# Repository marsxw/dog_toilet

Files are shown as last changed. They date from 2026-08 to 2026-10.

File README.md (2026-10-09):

# 狗厕所图纸 & 代码

模组：**ESP32-S3-WROOM-1-N16R8**（16MB Flash + 8MB Octal PSRAM；有时写作 N16S8，指同一类 8MB 外扩 RAM）。

## PC 虚拟环境

完整依赖与复现步骤见 **`environment.txt`**；一键安装：

```powershell
cd c:\Users\Siven\Desktop\dog_toilet
python -m venv venv
.\venv\Scripts\Activate.ps1
pip install -r requirements.txt
```

## 刷 MicroPython（COM3 示例）

须用 **SPIRAM_OCT** 固件，不要用不带 Octal PSRAM 的 `ESP32_GENERIC_S3-*.bin`（否则会报 `PSRAM chip is not connected`）。

```powershell
cd c:\Users\Siven\Desktop\dog_toilet
.\venv\Scripts\Activate.ps1
pip install esptool mpremote

python -m esptool --chip esp32s3 --port COM3 erase_flash
python -m esptool --chip esp32s3 --port COM3 --baud 460800 write_flash -z 0x0 `
  firmware\ESP32_GENERIC_S3-SPIRAM_OCT-20260824-v1.29.0.bin
```

## 上传 Python 到板子（COM3 示例）

先关掉 **bench_gui / Thonny** 等占用串口的程序。端口 `COM3` 按设备管理器修改。

```powershell
cd c:\Users\Siven\Desktop\dog_toilet\firmware
..\venv\Scripts\mpremote.exe connect COM3 soft-reset

..\venv\Scripts\mpremote.exe connect COM3 cp main.py :main.py
..\venv\Scripts\mpremote.exe connect COM3 cp bench.py :bench.py
..\venv\Scripts\mpremote.exe connect COM3 cp pins.py :pins.py
..\venv\Scripts\mpremote.exe connect COM3 cp motor.py :motor.py
..\venv\Scripts\mpremote.exe connect COM3 cp servo_ctrl.py :servo_ctrl.py
..\venv\Scripts\mpremote.exe connect COM3 cp config.py :config.py
..\venv\Scripts\mpremote.exe connect COM3 cp detector.py :detector.py
..\venv\Scripts\mpremote.exe connect COM3 cp web.py :web.py
..\venv\Scripts\mpremote.exe connect COM3 cp test_web.py :test_web.py
..\venv\Scripts\mpremote.exe connect COM3 cp ir_input.py :ir_input.py

..\venv\Scripts\mpremote.exe connect COM3 reset
```

若提示 `could not enter raw repl`，先 `soft-reset` 再 `cp`；若仍失败，按一下板子复位后重试。

## 客户模式 / 工程师模式

上电、断电重启后**默认客户模式**（自动感应冲水）。工程师模式只存在内存里，断电即回到客户模式。

1. 手机连接热点 `toilet_` + MAC 后 6 位（开放、无密码）。
2. **客户配置页：** [http://192.168.99.1](http://192.168.99.1)
3. **工程师测试页：** [http://192.168.99.1/test](http://192.168.99.1/test)  
   ESP32 热点只有一个本机 IP（`192.168.99.1`），工程师入口是该地址下的 `/test`。若写成 `192.168.99.99` 默认到不了板子。
4. **电脑 GUI：** 串口连接后会发 `ENG` 进入工程师模式；也可点「返回客户模式」（`CUST`）。断开串口会回到客户模式。

```powershell
.\venv\Scripts\Activate.ps1
python bench_gui\app.py
```

WiFi 默认开启 30 分钟，超时关闭后需重新上电。

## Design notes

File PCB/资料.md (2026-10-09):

对应板芯片的 MicroPython：[ESP32_GENERIC_S3](https://micropython.org/download/ESP32_GENERIC_S3/)  
模组：**ESP32-S3-WROOM-1-N16R8**（16MB Flash + **8MB Octal PSRAM**；部分资料写 N16S8，含义相同）。不要刷非 S3 固件。

**固件必须选 SPIRAM_OCT 版本**（文件名含 `SPIRAM_OCT`），例如仓库内  
`firmware/ESP32_GENERIC_S3-SPIRAM_OCT-20260824-v1.29.0.bin`。  
若误刷普通 `ESP32_GENERIC_S3-*.bin`，启动会报 `PSRAM chip is not connected` / `Failed to init external RAM`。

开发一个感应狗上厕并完成自动冲水的项目。

硬件：**红外传感器**判断占用；**冲水舵机**拉动冲水杆；**粉碎电机**由驱动芯片正反转；GPIO3 ADC 采电机电流（0.1Ω 采样电阻，放大 10.5 倍）。

## 接线 / GPIO

| 功能 | GPIO | 说明 |
|---|---|---|
| 红外输入 | **1** | 固定数字输入。触发（宠物在）= **高电平**；未触发 = **低电平** |
| 电机电流 ADC | **3** | 采样电阻 0.1Ω，放大 10.5 倍。`I = Vadc / 1.05` |
| 粉碎 IN1 | **11** | 驱动芯片输入。与 IN2 配合正反转，**禁止同时为高** |
| 粉碎 IN2 | **12** | 同上 |
| 冲水舵机 | **13** | 50 Hz PWM，脉宽 500–2500 µs 对应 0–180° |

粉碎电机逻辑：

| IN1 (11) | IN2 (12) | 动作 |
|---|---|---|
| 高 | 低 | 正转（粉碎开） |
| 低 | 高 | 反转 |
| 低 | 低 | 停止 |
| 高 | 高 | **禁止** |

电流超过 `firmware/motor.py` 中 `I_OVERCURRENT_A`（默认 4 A）时，调试模式下会停粉碎电机。

## 冲水动作

1. 舵机转到冲水角 `PRESS_DEG`（默认 90°），等待转动 + 保持
2. 舵机回到回位角 `RELEASE_DEG`（默认 20°）

默认回位 **0°**、按下 **70°**。工程师模式网页或串口 GUI 可改并保存到 `config.json`。

舵机每按下一轮冲水，粉碎剩余时间累加 `crush_s`（默认 **15 s**），电机一直转到剩余为 0。不并入冲水队列。电流超过 4 A 会停粉碎。

一次占用结束若冲水次数 > 1：按上面流程重复，两次之间间隔使用「冲水间隔」。

## 检测与冲水逻辑

空闲 → 占用中（GPIO1 高）→ 离开倒计时（GPIO1 由高变低）→ 冲水 → 空闲

- GPIO1 **高**：宠物在；若正处于离开倒计时，**取消冲水并重新占用**。
- GPIO1 由高变低：宠物离开，开始倒数；倒计时结束才冲水。
- 倒计时期间再次检测到高电平：倒计时清零，回到占用。
- 上电时若 GPIO1 已是低电平，不冲水，保持空闲。
- 冲水过程中电机动作做完再响应下一次检测。

## 客户模式 / 工程师模式

上电默认**客户模式**（自动冲水）。工程师模式不写 flash，断电即恢复客户模式。

| 入口 | 地址 / 操作 |
|---|---|
| 客户配置 | 连热点后打开 **http://192.168.99.1** |
| 工程师测试 | **http://192.168.99.1/test**（舵机 / 粉碎 / 电流） |
| 电脑 GUI | `python bench_gui\app.py`，串口发送 `ENG` 进入工程师模式 |

ESP32 热点本机 IP 只有 **192.168.99.1**，工程师页面是该 IP 的 `/test` 路径。

```powershell
cd c:\Users\Siven\Desktop\dog_toilet
.\venv\Scripts\Activate.ps1
python bench_gui\app.py
```

连接 USB 串口（115200），调节舵机角度、粉碎正反转，并看 GPIO3 电流；测好后改 `RELEASE_DEG` / `PRESS_DEG`。

## 网页（客户）

手机连接 ESP32 热点后打开 **http://192.168.99.1** 配置感应和冲水参数。

- 上电后 WiFi 默认开启 **30 分钟**，超时自动关闭。
- 热点名称：`toilet_` + MAC 后 6 位。
- 参数掉电保存；界面中英文可切换。

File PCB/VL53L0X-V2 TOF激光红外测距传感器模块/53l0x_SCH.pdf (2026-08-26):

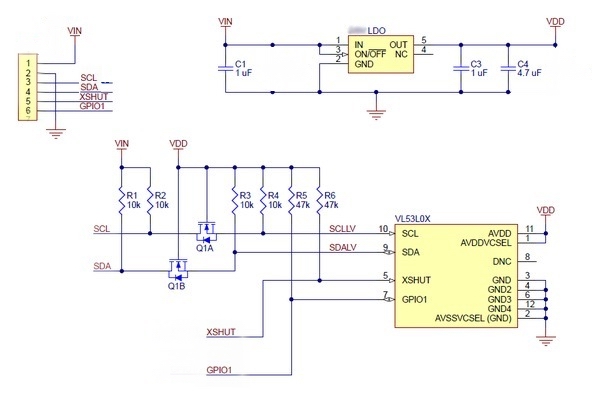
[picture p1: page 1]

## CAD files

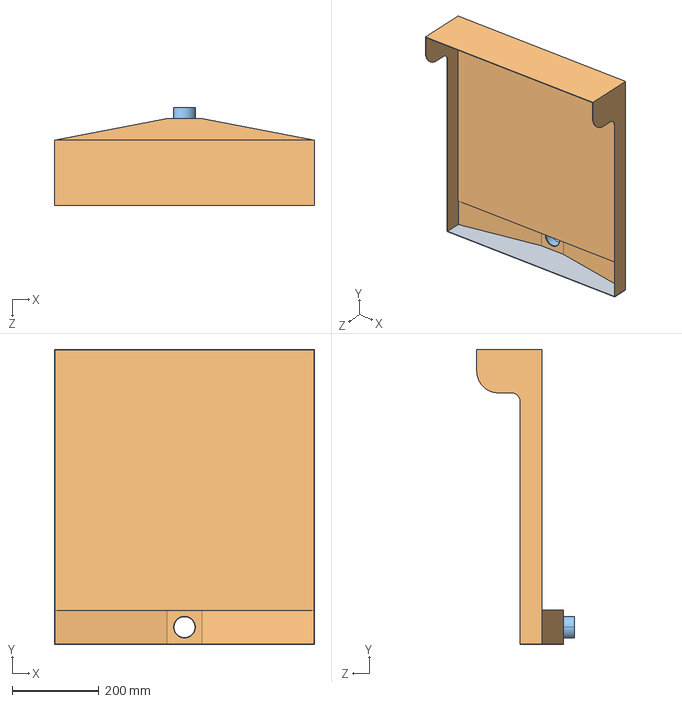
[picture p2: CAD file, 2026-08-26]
机械结构/收集盆v1.STEP
600.0 x 680.0 x 225.0 mm

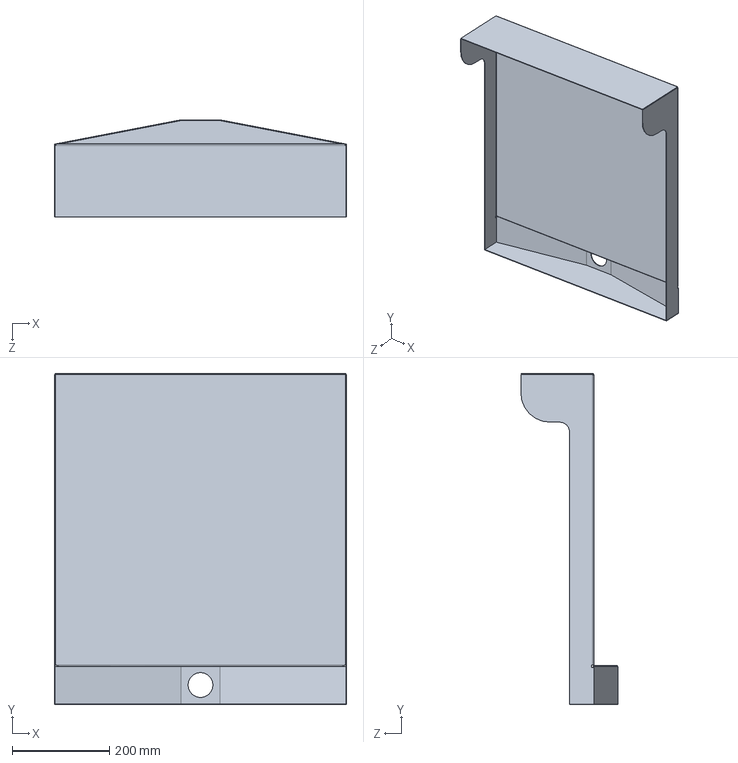
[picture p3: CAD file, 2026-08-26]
机械结构/收集盆_钣金.SLDPRT
600.0 x 680.0 x 200.0 mm

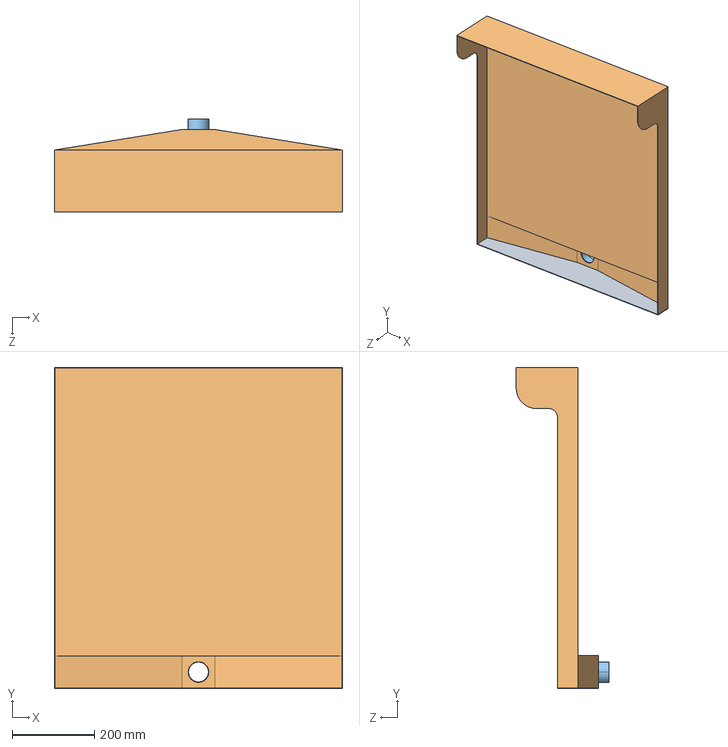
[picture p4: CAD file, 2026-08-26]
机械结构/收集盆70.STEP
700.0 x 780.0 x 225.0 mm

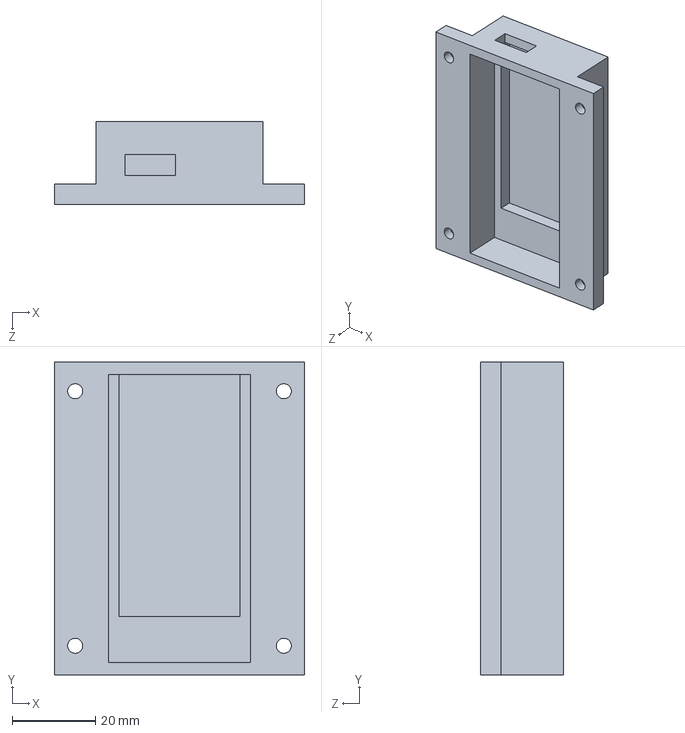
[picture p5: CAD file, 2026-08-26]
机械结构/pcb外壳底.STEP
60.0 x 75.0 x 20.0 mm

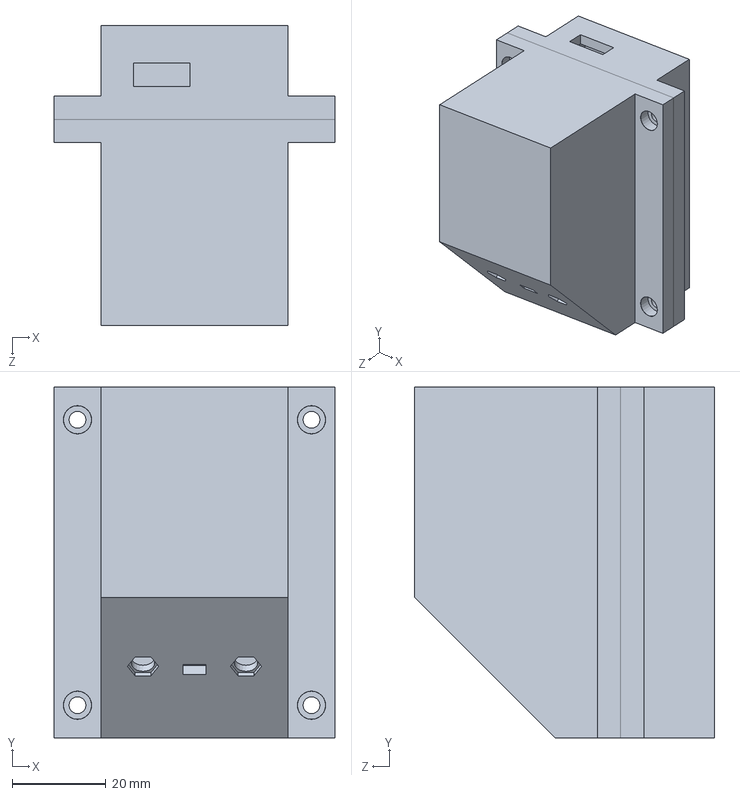
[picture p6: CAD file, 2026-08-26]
机械结构/pcb外盒.SLDPRT
60.0 x 75.0 x 64.0 mm

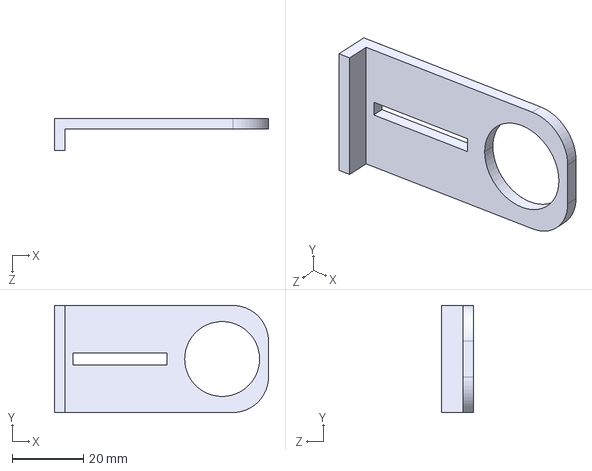
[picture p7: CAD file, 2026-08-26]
机械结构/1.STEP
60.0 x 30.0 x 9.00 mm

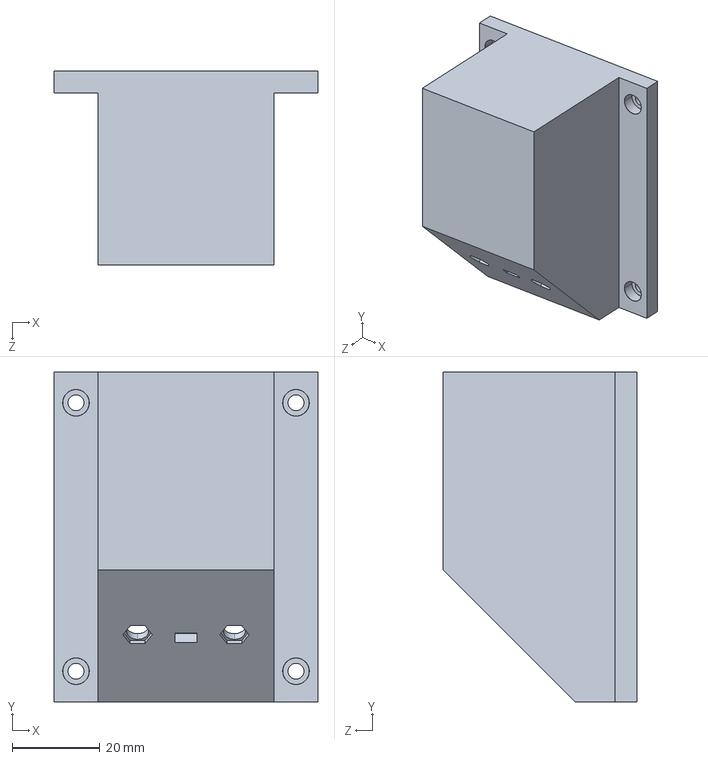
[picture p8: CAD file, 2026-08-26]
机械结构/pcb外壳顶.STEP
60.0 x 75.0 x 44.0 mm

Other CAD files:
机械结构/收集盆.STEP
机械结构/1.SLDPRT
机械结构/pcb外壳底.SLDPRT
机械结构/pcb外壳顶.3mf
机械结构/pcb外壳顶.SLDPRT
机械结构/收集盆70.SLDPRT
机械结构/收集盆v1.SLDPRT

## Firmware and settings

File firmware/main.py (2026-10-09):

import asyncio
import json
import sys
import time

try:
    import uselect
except ImportError:
    uselect = None

from config import DEFAULTS, detector_cfg, load_config, sanitize, save_config
from detector import Detector, remain_s
from ir_input import is_present, make_ir_pin
from motor import I_OVERCURRENT_A, CrushMotor, MotorCurrent
from servo_ctrl import PRESS_HOLD_S, SERVO_MOVE_S, FlushServo
from bench import Bench
from web import AP_IP, WebServer, start_ap, stop_ap


class App:
    def __init__(self):
        self.cfg = load_config()
        self.error = ""
        self.ssid = ""
        self.wifi_on = False
        self.ir_present = False
        self._boot_ms = time.ticks_ms()
        self.detector = Detector(detector_cfg(self.cfg))
        self._flushing = False
        self._flush_lock = asyncio.Lock()
        self.flush_phase = ""
        self._wait_start_ms = 0
        self._wait_ms = 0
        self.servo = FlushServo(
            release_deg=self.cfg["release_deg"],
            press_deg=self.cfg["press_deg"],
        )
        self.crush = CrushMotor(direction=self.cfg.get("crush_dir", "fwd"))
        self.current = MotorCurrent()
        self.ir = make_ir_pin()
        self.bench = Bench(self.servo, self.crush, self.current, self.ir)
        self.engineer_mode = False
        self._crush_remain_ms = 0
        self._crush_last_ms = 0

    def enter_engineer(self):
        self.engineer_mode = True

    def leave_engineer(self):
        was = self.engineer_mode
        self.engineer_mode = False
        self.bench.idle_outputs()
        self._crush_stop()
        if was:
            self.detector.end_flush(time.ticks_ms())
            self._flushing = False
            self.flush_phase = ""
            self._wait_ms = 0

    def bench_cmd(self, line):
        cmd = (line or "").strip().split()
        name = cmd[0].upper() if cmd else ""
        if name in ("ENG", "ENGINEER", "BENCH"):
            self.enter_engineer()
            return "OK ENGINEER"
        if name in ("CUST", "CUSTOMER"):
            self.leave_engineer()
            return "OK CUSTOMER"
        if name == "MODE":
            return "MODE engineer" if self.engineer_mode else "MODE customer"
        if name == "PING":
            return "PONG"
        if name == "SERVOCFG" and len(cmd) >= 3:
            self.enter_engineer()
            return self.set_servo_angles(cmd[1], cmd[2], save=True, move_home=True)
        if name == "HOME" and len(cmd) >= 2:
            self.enter_engineer()
            return self.set_servo_angles(cmd[1], self.cfg["press_deg"], save=True, move_home=True)
        if name == "PRESSDEG" and len(cmd) >= 2:
            self.enter_engineer()
            return self.set_servo_angles(self.cfg["release_deg"], cmd[1], save=True, move_home=False)
        if name == "SAVE":
            self.cfg = save_config(self.cfg)
            return "OK SAVE release={:.1f} press={:.1f} crush={}".format(
                self.cfg["release_deg"], self.cfg["press_deg"], self.cfg["crush_dir"]
            )
        if name == "CRUSHDIR" and len(cmd) >= 2:
            self.enter_engineer()
            return self.set_crush_dir(cmd[1], save=True)
        hardware = name in (
            "SERVO",
            "PRESS",
            "RELEASE",
            "FWD",
            "REV",
            "STOP",
            "CRUSH",
        )
        if hardware and not self.engineer_mode:
            self.enter_engineer()
        return self.bench.handle(line)

    def set_servo_angles(self, release_deg, press_deg, save=True, move_home=False):
        cfg = dict(self.cfg)
        cfg["release_deg"] = release_deg
        cfg["press_deg"] = press_deg
        if save:
            self.cfg = save_config(cfg)
        else:
            self.cfg = sanitize(cfg)
        self.servo.set_limits(self.cfg["release_deg"], self.cfg["press_deg"])
        if move_home:
            self.servo.release()
        return "OK SERVOCFG release={:.1f} press={:.1f}".format(
            self.cfg["release_deg"], self.cfg["press_deg"]
        )

    def set_crush_dir(self, direction, save=True):
        cfg = dict(self.cfg)
        cfg["crush_dir"] = direction
        if save:
            self.cfg = save_config(cfg)
        else:
            self.cfg = sanitize(cfg)
        self.crush.set_direction(self.cfg["crush_dir"])
        if self.crush.is_on():
            self.crush.on()
        return "OK CRUSHDIR {}".format(self.cfg["crush_dir"])

    def engineer_status(self):
        snap = self.bench.snapshot()
        snap["mode"] = "engineer" if self.engineer_mode else "customer"
        snap["error"] = self.error
        snap["release_deg"] = float(self.cfg["release_deg"])
        snap["press_deg"] = float(self.cfg["press_deg"])
        snap["crush_dir"] = self.cfg.get("crush_dir", "fwd")
        return snap

    def engineer_status_json(self):
        st = self.engineer_status()
        st["trip"] = st.get("trip") is not None
        return json.dumps(st)

    def status(self):
        timeout_ms = int(self.cfg["wifi_timeout_s"]) * 1000
        elapsed = time.ticks_diff(time.ticks_ms(), self._boot_ms)
        remain_s = (timeout_ms - elapsed) // 1000
        if remain_s < 0:
            remain_s = 0
        if self.engineer_mode:
            remain_s = int(self.cfg["wifi_timeout_s"])
        now = time.ticks_ms()
        state = self.detector.state
        wait_s = 0
        if state == "leaving":
            wait_s = self.detector.leave_remain_s(now)
        elif state == "flushing":
            wait_s = self.wait_remain_s()
        return {
            "state": state,
            "ir_present": self.ir_present,
            "leave_remain_s": self.detector.leave_remain_s(now),
            "hold_remain_s": self.detector.hold_remain_s(now),
            "flush_phase": self.flush_phase,
            "wait_s": wait_s,
            "error": self.error,
            "wifi_remain_s": remain_s,
            "mode": "engineer" if self.engineer_mode else "customer",
        }

    def wait_remain_s(self):
        if self._wait_ms <= 0:
            return 0
        elapsed = time.ticks_diff(time.ticks_ms(), self._wait_start_ms)
        remain_ms = self._wait_ms - elapsed
        return remain_s(remain_ms)

    def _begin_wait(self, seconds):
        self._wait_start_ms = time.ticks_ms()
        self._wait_ms = int(float(seconds) * 1000)

    def status_json(self):
        return json.dumps(self.status())

    def apply_form(self, form):
        cfg = dict(self.cfg)
        keys = [
            "leave_delay_s",
            "trigger_mode",
            "trigger_hold_s",
            "flush_count",
            "flush_interval_s",
            "crush_s",
            "lang",
        ]
        for key in keys:
            if key in form and form[key] != "":
                cfg[key] = form[key]
        self.cfg = save_config(cfg)
        self.detector.cfg = detector_cfg(self.cfg)

    def reset_params(self):
        lang = self.cfg.get("lang") or "zh"
        cfg = dict(DEFAULTS)
        cfg["lang"] = lang
        cfg["release_deg"] = self.cfg.get("release_deg", DEFAULTS["release_deg"])
        cfg["press_deg"] = self.cfg.get("press_deg", DEFAULTS["press_deg"])
        cfg["crush_dir"] = self.cfg.get("crush_dir", DEFAULTS["crush_dir"])
        self.cfg = save_config(cfg)
        self.detector.cfg = detector_cfg(self.cfg)
        self.servo.set_limits(self.cfg["release_deg"], self.cfg["press_deg"])
        self.crush.set_direction(self.cfg["crush_dir"])

    def _crush_start(self, seconds):
        add_ms = int(float(seconds) * 1000)
        if add_ms <= 0:
            return
        now = time.ticks_ms()
        if self._crush_remain_ms <= 0:
            self._crush_last_ms = now
            self._crush_remain_ms = 0
        self._crush_remain_ms += add_ms
        self.crush.set_direction(self.cfg.get("crush_dir", "fwd"))
        self.crush.on()

    def _crush_stop(self):
        self._crush_remain_ms = 0
        self._crush_last_ms = 0
        self.crush.off()

    def _crush_poll(self):
        if self.engineer_mode:
            return
        if self._crush_remain_ms <= 0:
            if self.crush.is_on():
                self.crush.off()
            return
        now = time.ticks_ms()
        elapsed = time.ticks_diff(now, self._crush_last_ms)
        if elapsed > 0:
            self._crush_remain_ms -= elapsed
            self._crush_last_ms = now
        if self._crush_remain_ms <= 0:
            self._crush_stop()
            return
        if not self.crush.is_on():
            self.crush.on()
            return
        try:
            _v, amps, _raw = self.current.read(8)
            if amps >= I_OVERCURRENT_A:
                self._crush_stop()
                self.error = "crush overcurrent {:.2f}A".format(amps)
        except Exception:
            pass

    async def _sleep_flush(self, seconds):
        end = time.ticks_add(time.ticks_ms(), int(float(seconds) * 1000))
        while time.ticks_diff(end, time.ticks_ms()) > 0:
            if self.engineer_mode:
                return False
            self._crush_poll()
            remain = time.ticks_diff(end, time.ticks_ms())
            await asyncio.sleep_ms(min(80, max(10, remain)))
        return True

    async def flush(self):
        async with self._flush_lock:
            self._flushing = True
            try:
                n = int(self.cfg["flush_count"])
                interval = float(self.cfg["flush_interval_s"])
                crush_s = float(self.cfg.get("crush_s", 15))
                for i in range(n):
                    if self.engineer_mode:
                        break
                    self.flush_phase = "flushing"
                    self._begin_wait(SERVO_MOVE_S + PRESS_HOLD_S + SERVO_MOVE_S)
                    self.servo.press()
                    self._crush_start(crush_s)
                    if not await self._sleep_flush(SERVO_MOVE_S + PRESS_HOLD_S):
                        break
                    self.servo.release()
                    if not await self._sleep_flush(SERVO_MOVE_S):
                        break
                    if i < n - 1:
                        self.flush_phase = "refill"
                        self._begin_wait(interval)
                        if not await self._sleep_flush(interval):
                            break
            finally:
                if self.engineer_mode:
                    self._crush_stop()
                if not self.engineer_mode:
                    self.servo.release()
                self.flush_phase = ""
                self._wait_ms = 0
                self.detector.end_flush(time.ticks_ms())
                self._flushing = False

    async def sensor_loop(self):
        await asyncio.sleep_ms(200)
        sample_ms = int(self.cfg["sample_ms"])
        while True:
            self._crush_poll()
            if not self._flushing and not self.engineer_mode:
                try:
                    present = is_present(self.ir.value())
                    self.ir_present = present
                    self.error = ""
                    event = self.detector.tick(present, time.ticks_ms())
                    if event == "start_flush":
                        await self.flush()
                except Exception as exc:
                    self.error = str(exc)
                    self.servo.release()
            elif self.engineer_mode:
                try:
                    self.ir_present = is_present(self.ir.value())
                    self.error = ""
                except Exception as exc:
                    self.error = str(exc)
            await asyncio.sleep_ms(sample_ms)

    def _serial_reply(self, line):
        sys.stdout.write(line + "\n")
        try:
            sys.stdout.flush()
        except AttributeError:
            pass

    def _serial_feed(self, buf, chunk):
        buf += chunk.replace("\r\n", "\n").replace("\r", "\n")
        while "\n" in buf:
            line, buf = buf.split("\n", 1)
            line = line.strip()
            if not line:
                continue
            try:
                reply = self.bench_cmd(line)
                if reply:
                    self._serial_reply(reply)
            except Exception as exc:
                self._serial_reply("ERR " + str(exc))
        return buf

    async def serial_loop(self):
        # USB 串口 read 可能阻塞整个 asyncio，必须先让出 CPU，等热点起来后再读
        while not self.wifi_on:
            await asyncio.sleep_ms(50)
        await asyncio.sleep_ms(300)
        poll = None
        if uselect is not None:
            try:
                poll = uselect.poll()
                poll.register(sys.stdin, uselect.POLLIN)
            except Exception:
                poll = None
        buf = ""
        while True:
            await asyncio.sleep_ms(40)
            if poll is None:
                continue
            try:
                ready = poll.poll(0)
            except Exception:
                ready = []
            if not ready:
                continue
            try:
                chunk = sys.stdin.read(1)
            except Exception:
                chunk = ""
            if chunk:
                buf = self._serial_feed(buf, chunk)

    async def wifi_loop(self):
        if not self.wifi_on:
            _ap, self.ssid = start_ap()
            self.wifi_on = True
            print("AP", self.ssid, "http://%s  engineer http://%s/test" % (AP_IP, AP_IP))
        server = WebServer(self)
        await server.start()
        timeout_ms = int(self.cfg["wifi_timeout_s"]) * 1000
        while True:
            if self.engineer_mode:
                await asyncio.sleep(1)
                continue
            if time.ticks_diff(time.ticks_ms(), self._boot_ms) >= timeout_ms:
                break
            await asyncio.sleep(1)
        print("WiFi timeout, stopping AP")
        server.close()
        stop_ap()
        self.wifi_on = False


async def main():
    try:
        ap, ssid = start_ap()
        print("AP", ssid, "http://%s  engineer http://%s/test" % (AP_IP, AP_IP))
    except Exception as exc:
        print("ap fail", exc)
        ap, ssid = None, ""
    app = App()
    if ap is not None:
        app.ssid = ssid
        app.wifi_on = True
    await asyncio.gather(app.sensor_loop(), app.wifi_loop(), app.serial_loop())


try:
    asyncio.run(main())
except Exception as exc:
    print("fatal", exc)
    raise

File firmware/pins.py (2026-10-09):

# ESP32-S3-WROOM-1（新 PCB IO）

# 红外：固定 GPIO1 数字输入。触发=高、未触发=低
PIN_IR = 1

# 电机电流：采样电阻 0.1Ω，放大 10.5 倍后进 ADC
PIN_IADC = 3

# 粉碎电机驱动芯片 IN1 / IN2（禁止两脚同时为高）
PIN_CRUSH_IN1 = 11
PIN_CRUSH_IN2 = 12

# 冲水舵机 PWM
PIN_SERVO = 13

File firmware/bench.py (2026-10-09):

"""
工程师测试：串口命令与网页 /test 共用同一套硬件动作。
上电默认客户模式；工程师模式仅在内存中，断电后回到客户模式。
"""

import sys
import time

from ir_input import format_ir_line, is_present, make_ir_pin, raw_value
from motor import I_GAIN, I_OVERCURRENT_A, R_SENSE_OHM, CrushMotor, MotorCurrent
from pins import PIN_CRUSH_IN1, PIN_CRUSH_IN2, PIN_IADC, PIN_IR, PIN_SERVO
from servo_ctrl import FlushServo


def _parse_cmd(line):
    line = (line or "").strip()
    if not line:
        return None, None
    parts = line.split()
    return parts[0].upper(), parts[1:]


class Bench:
    def __init__(self, servo=None, crush=None, current=None, ir_pin=None):
        self.servo = servo or FlushServo()
        self.crush = crush or CrushMotor()
        self.current = current or MotorCurrent()
        self.ir_pin = ir_pin if ir_pin is not None else make_ir_pin()

    def ir_report(self):
        raw = raw_value(self.ir_pin)
        present = is_present(raw)
        return format_ir_line(raw, present)

    def current_sample(self):
        try:
            v, a, raw = self.current.read()
        except Exception as exc:
            line = "I err={}".format(exc)
            return line, None, 0.0, 0.0, 0
        line = "I gpio={} raw={} v={:.3f} a={:.2f}".format(
            self.current.pin_num, raw, v, a
        )
        tripped = None
        if self.crush.is_on() and a >= I_OVERCURRENT_A:
            self.crush.off()
            tripped = a
        return line, tripped, v, a, raw

    def snapshot(self):
        raw = raw_value(self.ir_pin)
        i_line, tripped, v, a, i_raw = self.current_sample()
        return {
            "ir_raw": raw,
            "ir_present": bool(is_present(raw)),
            "servo": float(self.servo.angle),
            "crush": 1 if self.crush.is_on() else 0,
            "i_v": v,
            "i_a": a,
            "i_raw": i_raw,
            "i_line": i_line,
            "trip": tripped,
            "release_deg": float(self.servo.release_deg),
            "press_deg": float(self.servo.press_deg),
            "crush_dir": getattr(self.crush, "direction", "fwd"),
        }

    def idle_outputs(self):
        self.crush.off()
        self.servo.release()

    def handle(self, line):
        cmd, args = _parse_cmd(line)
        if cmd is None:
            return ""
        if cmd == "PING":
            return "PONG"
        if cmd in ("ENG", "ENGINEER", "BENCH"):
            return "OK ENGINEER"
        if cmd in ("CUST", "CUSTOMER"):
            return "OK CUSTOMER"
        if cmd == "MODE":
            return "MODE"
        if cmd == "IR":
            return self.ir_report()
        if cmd == "SERVO" and len(args) == 1:
            self.servo.set_angle(float(args[0]))
            return "OK SERVO {:.1f}".format(self.servo.angle)
        if cmd == "PRESS":
            self.servo.press()
            return "OK PRESS {:.1f}".format(self.servo.angle)
        if cmd == "RELEASE":
            self.servo.release()
            return "OK RELEASE {:.1f}".format(self.servo.angle)
        if cmd == "FWD":
            self.crush.forward()
            return "OK FWD"
        if cmd == "REV":
            self.crush.reverse()
            return "OK REV"
        if cmd == "STOP":
            self.crush.off()
            return "OK STOP"
        if cmd == "CRUSH" and len(args) == 1:
            if args[0] in ("1", "ON", "on"):
                self.crush.on()
                return "OK CRUSH ON"
            self.crush.off()
            return "OK CRUSH OFF"
        if cmd in ("I", "CURRENT"):
            line, tripped, _v, _a, _raw = self.current_sample()
            if tripped is not None:
                return line + " TRIP a={:.2f}".format(tripped)
            return line
        if cmd == "STATUS":
            snap = self.snapshot()
            line = "servo={:.1f} ir={} crush={} {}".format(
                snap["servo"],
                snap["ir_raw"],
                snap["crush"],
                snap["i_line"],
            )
            if snap["trip"] is not None:
                line += " TRIP"
            return line
        return "ERR unknown"


def _reply(line):
    sys.stdout.write(line + "\n")
    try:
        sys.stdout.flush()
    except AttributeError:
        pass


def run_bench():
    bench = Bench()
    _reply(
        "BENCH OK IR={} SERVO={} CRUSH={} {} IADC={} Rs={} G={} cmds: ENG CUST IR SERVO PRESS RELEASE CRUSH I".format(
            PIN_IR,
            PIN_SERVO,
            PIN_CRUSH_IN1,
            PIN_CRUSH_IN2,
            PIN_IADC,
            R_SENSE_OHM,
            I_GAIN,
        )
    )
    while True:
        line = sys.stdin.readline()
        if not line:
            time.sleep_ms(20)
            continue
        cmd, _args = _parse_cmd(line)
        if cmd is None:
            continue
        try:
            reply = bench.handle(line)
            if reply:
                _reply(reply)
        except Exception as exc:
            _reply("ERR " + str(exc))


if __name__ == "__main__":
    run_bench()

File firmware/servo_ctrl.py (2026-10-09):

from machine import PWM, Pin

from pins import PIN_SERVO

SERVO_FREQ_HZ = 50
RELEASE_DEG = 0
PRESS_DEG = 70
SERVO_MOVE_S = 1.0
PRESS_HOLD_S = 1.0


class Servo:
    def __init__(self, pin=PIN_SERVO, release_deg=RELEASE_DEG):
        self.pin_num = int(pin)
        self.angle = float(release_deg)
        self.pwm = PWM(Pin(self.pin_num), freq=SERVO_FREQ_HZ)
        self.set_angle(release_deg)

    def set_angle(self, deg):
        deg = max(0.0, min(180.0, float(deg)))
        self.angle = deg
        us = 500.0 + (deg / 180.0) * 2000.0
        self.pwm.duty_ns(int(us * 1000))

    def attach(self, pin, release_deg=RELEASE_DEG):
        self.pwm.deinit()
        self.__init__(pin, release_deg)

    def deinit(self):
        try:
            self.pwm.deinit()
        except OSError:
            pass


class FlushServo(Servo):
    def __init__(
        self,
        pin=PIN_SERVO,
        release_deg=RELEASE_DEG,
        press_deg=PRESS_DEG,
    ):
        super().__init__(pin, release_deg)
        self.release_deg = float(release_deg)
        self.press_deg = float(press_deg)

    def set_limits(self, release_deg, press_deg):
        self.release_deg = max(0.0, min(180.0, float(release_deg)))
        self.press_deg = max(0.0, min(180.0, float(press_deg)))

    def press(self):
        self.set_angle(self.press_deg)

    def release(self):
        self.set_angle(self.release_deg)

    def down(self):
        self.press()

    def up(self):
        self.release()

    def stop(self):
        self.release()

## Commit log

2026-08-26 初始化仓库：提交红外感应自动冲水固件、网页配置和机械结构文件。
    [1.SLDPRT, 1.STEP, pcb外壳底.SLDPRT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]
2026-09-30 Add PC venv export, bench GUI, and new PCB firmware IO.
    Document environment reproduction in environment.txt and requirements.txt; update motor control, serial bench, and hardware docs for ESP32-S3 N16R8.
2026-10-08 Adapt firmware to servo flush, dual-pin crush driver, and filtered current sense.
2026-10-09 Add customer and engineer modes with crush and servo settings.
    Boot into the customer AP at 192.168.99.1, keep engineer tools on /test and serial, and persist flush crush time plus motor direction.
2026-10-09 Run crush on press with accumulated remaining time.
    Start the crush motor when the flush lever presses, add crush duration per press, and keep it off the flush wait queue.
